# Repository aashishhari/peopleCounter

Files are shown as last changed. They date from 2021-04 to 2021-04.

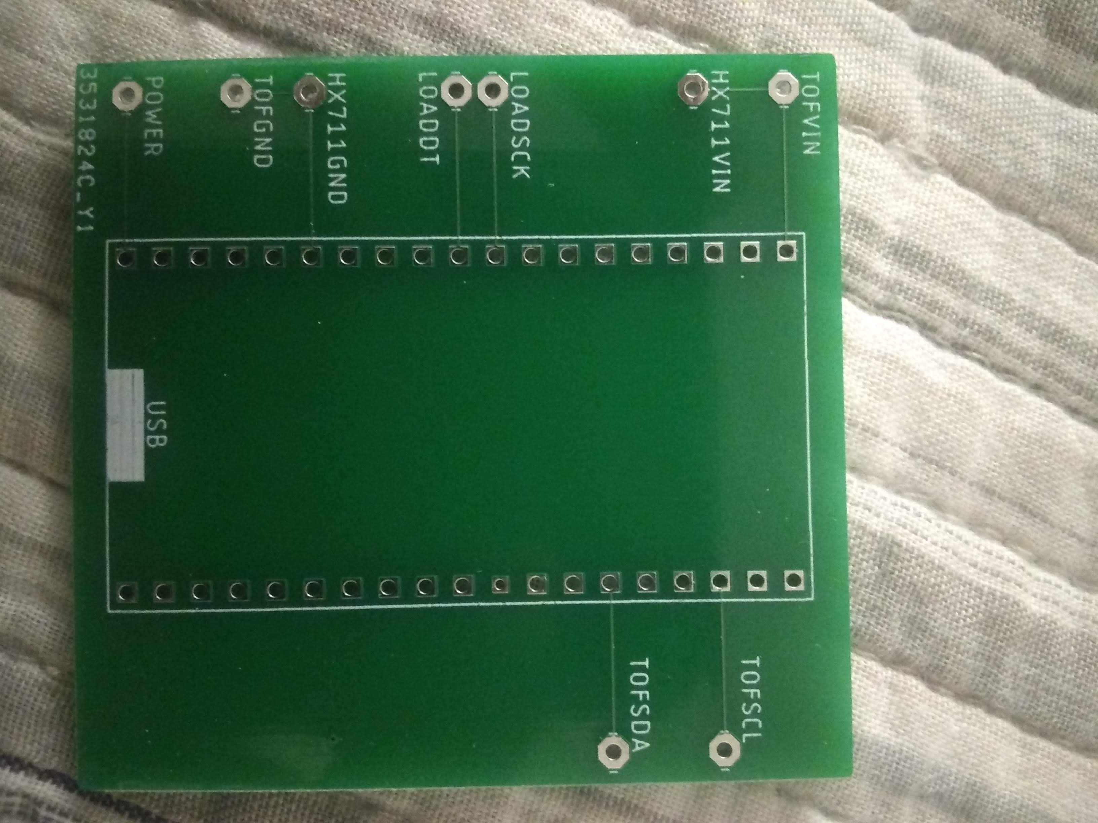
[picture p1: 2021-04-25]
PCB_Photos/PCB.jpg

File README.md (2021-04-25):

# Welcome to Team3's Project Repo for EECS 300

 __In this repo, you'll find our final project code within the `finalDemo` folder.  Note the requirements at the bottom.__
 
 > `EECS300pcb` contains all the parts of the Eagle PCB Project (schematic, pcb view, gerber, drill, etc.).
 
 > `GerberFiles` contains gerber and drill files sent to JLCPCB for final PCB production.
 
 > `TestingData` contains the testing data referenced in our final report.
 
 > `PCB_Photos` contains an image of the final manafactured PCB and also an image of the PCB design in its layered form.

 Additionally, a couple extra files and directories contain a few different implementations we were experimenting with throughout the process.  
 *finalcode_multicore.ino* - contains a prototype multicore version of our design.

__Required Libraries/Dependencies (These need to be installed to run):__
 1. SparkFun_VL53L1X *Version 1.2.9*
 2. Arduino Development Environment (with arduino-esp32 core from Espressif)

__Note: You may need to input WiFi information, SSID, Password, Host ID to compile finalDemo code with no errors__

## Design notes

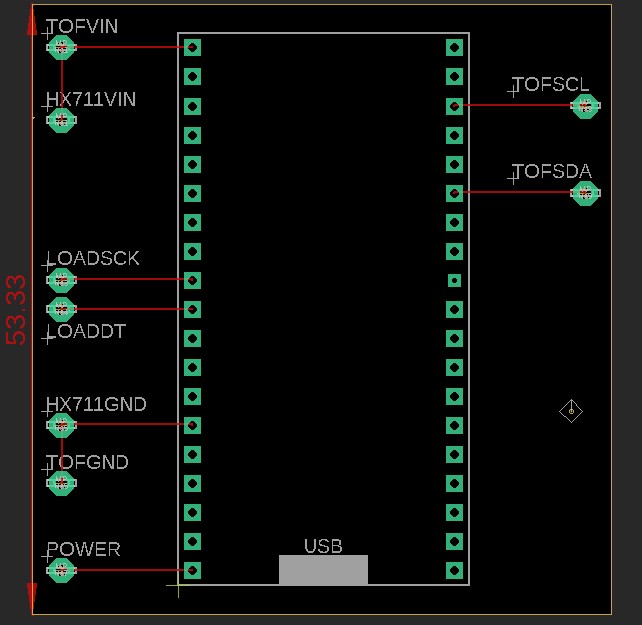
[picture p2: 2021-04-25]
PCB_Photos/PCB_DesignLayers.jpg

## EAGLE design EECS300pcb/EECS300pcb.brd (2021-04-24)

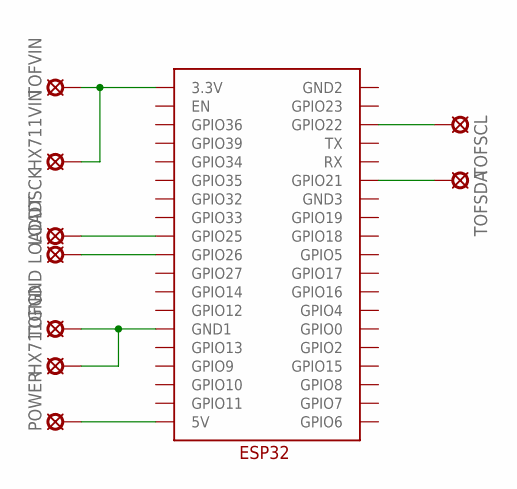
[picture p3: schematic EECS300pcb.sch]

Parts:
HX711GND, HX711VIN: LSP10
LOADDT: LSP10
LOADSCK: LSP10
POWER: LSP10
TOFGND: LSP10
TOFSCL: LSP10
TOFSDA: LSP10
TOFVIN: LSP10
U$2: ESP32

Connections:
unnamed: HX711VIN.MP, TOFVIN.MP, U$2.3.3V
unnamed: LOADSCK.MP, U$2.GPIO25
unnamed: LOADDT.MP, U$2.GPIO26
unnamed: HX711GND.MP, TOFGND.MP, U$2.GND1
unnamed: POWER.MP, U$2.5V
unnamed: TOFSCL.MP, U$2.GPIO22
unnamed: TOFSDA.MP, U$2.GPIO21

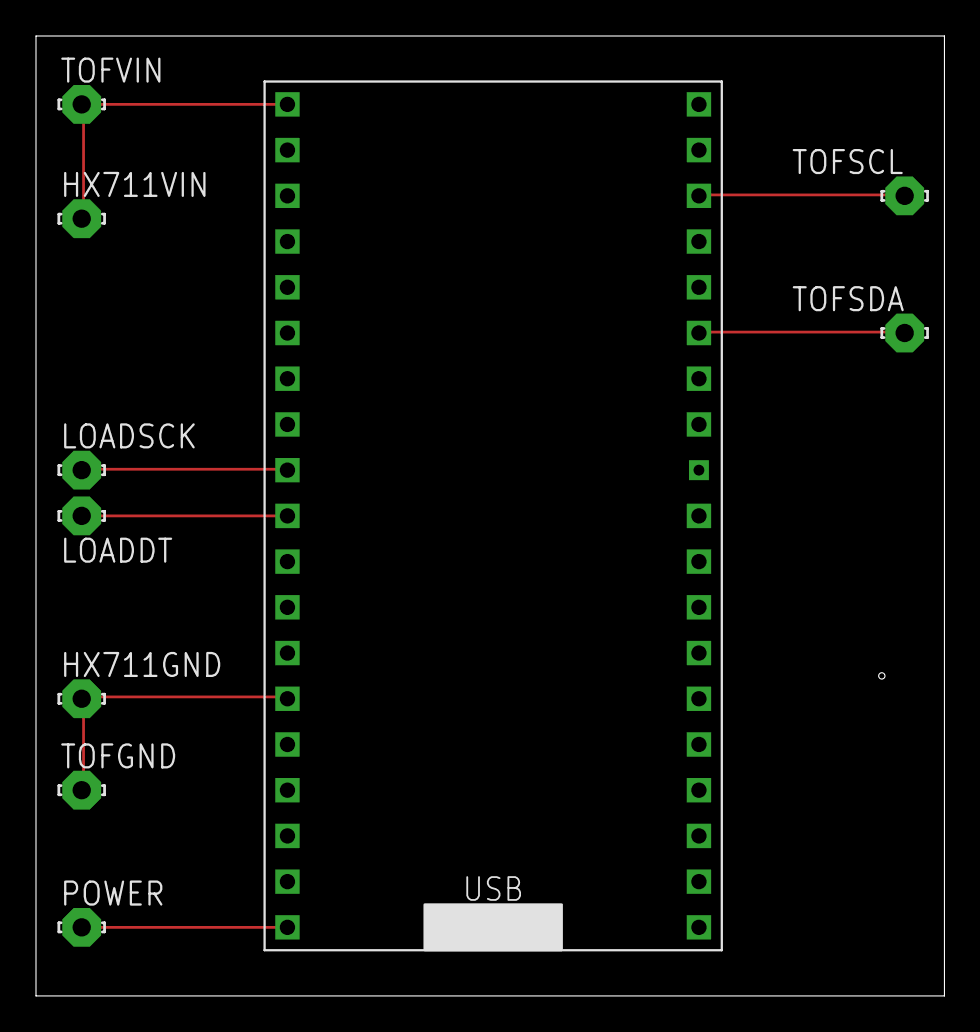
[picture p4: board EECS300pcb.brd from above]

Board: 2 copper layers, 50.5 x 53.3 mm, 10 parts (0 on the bottom side), 7 nets.

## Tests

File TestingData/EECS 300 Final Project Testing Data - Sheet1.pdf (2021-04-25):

Experiment 1 | Description: step around the board a certain amount of times, and determine the edge step efficiency | Size
Trial 1 | Trial 2 | Trial 3 | Darren's board | 28cm x 64cm x 2cm
Registered Steps (Jason)
Resigistered Steps (Darren) | 12 | 12 | 6 | Jason's board
Resigistered Steps (Darren) Day 2 | 12 | 8 | 13
Total Steps | 16 | 16 | 16
Edge step efficiency (%) (Jason)
Edge step efficiency (%) (Darren) | 75 | 75 | 37.5
Edge step efficiency (%) (Darren) | 75 | 50 | 81.25
Average edge step efficiency | 65.625 | (higher is better)
Nptes: | During the second and third trial, my foot almost flipped the wooden board by stepping on the edges of the board, and the board was unable to recognize steps for a few seconds.
| A possible issue is that the board is not the best, because the wooden board I found was kind of old. The board isn't completely level, so we may want to buy another whole set of amazon sensors and buy a brand new board if we want to go with these sensors for the final build.
Experiment 2 | Description: step on a certain spot of the board repeatedly (1 second between each step to let load sensor reset to 0) according to the image to the right
Trial 1 | Trial 2 | Trial 3 | Trial 4 | Trial 5 | Trial 6 | Trial 7 | Trial 8 | Trial 9 (control)
Resigistered Steps (Darren) | 19 | | 20 | | 17 | | 6 | | 20
Resigistered Steps (Jason) | 18 | | 19 | | | | 3 | | 16
Total Steps | 20 | | 20 | | 20 | | 20 | | 20
Edge step efficiency (%) (Darren) | 95 | #DIV/0! | 100 | #DIV/0! | 85 | #DIV/0! | 30 | #DIV/0! | 100
Edge step efficiency (%) (Jason) | 90 | #DIV/0! | 95 | #DIV/0! | 0 | #DIV/0! | 15 | #DIV/0! | 80
Average edge step efficiency | 76.66666667 | | (higher is better)
Notes/conclusions: | Eliminated trials 2, 4, 6, and 8 because we felt that they are already covered by the other 5 trials
| Choosing the right board for the pressure plate is just as important as getting the load sensors working
| The board is not stable, and so we should consider ways to stabilize the board from moving around, while they are getting pressed
| Maybe consider lowering the threshold weight
| Might want to use a sturdier material for final design (not wood)
| Board is acting like a table that is not level (possible issue with Darren's pressure plate)
| It is fine to apply all the weight on one of the four sensors, as long as, an appropriate board is chosen.
Experiment 3 (Darren's trials) | Description: Using a weight lighter than the threshold weight and dropping it in the center of the pressure plate to see if the pressure plate counts weights lighter than the set threshold weight
Trial 1 | Trial 2 | Trial 3
Resigistered Steps (Darren) | 0 | 0 | 0
Resigistered Steps (Jason)
Total Steps | 10 | 10 | 10
Edge step efficiency (%) (Darren) | 0 | 0 | 0
Edge step efficiency (%) (Jason) | 0 | 0 | 0
Average edge step efficiency | 0 | | (lower is better)
Nptes: | Seems like the pressure plate does not have any issues with not making accidental counts when a weight lower than the threshold has been put on it.

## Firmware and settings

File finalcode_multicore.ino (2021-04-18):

#include "hal.h"
#include "HX711.h"
#include "soc/rtc.h"
#include "hal.h"

#include <Wire.h>
#include <SparkFun_VL53L1X.h>
#include <WiFi.h>

/* Multicore */
TaskHandle_t main;
TaskHandle_t wifiUpdate;
void main(void *pvParameters);
void wifiUpdate(void *pvParameters);
/** done **/

/** WIFI Globals **/
const char* ssid = "NETGEAR92";
const char* password =  "youngtrumpet129";
const uint16_t port = 8090;
const char * host = "192.168.1.16";
WiFiClient client;
/** done **/

/** TOF Globals **/
static const int NOBODY = 0;
static const int SOMEONE = 1;
static const int LEFT = 0;
static const int RIGHT = 1;
static int center[2] = {167, 231}; // andrea's suggested value also try
int zone = 0;

#define DIST_THRESHOLD                               1600  // mm
#define ROWS_OF_SPADS                                4 // 8x16 SPADs ROI
#define TIMING_BUDGET                                33  // was 20 ms, I found 33 ms has better succes rate with lower reflectance target
#define ROI_WIDTH                                    4
#define ROI_HEIGHT                                   4
SFEVL53L1X sensor(Wire);
int ProcessPeopleCountingData(int16_t Distance, uint8_t zone);
int tofCount = 0;
int tofOldCount = 0;
/** done **/

/** Load Sensor Globals **/
HX711 scale;
float threshold = 1000; // kg
float reading = 0;
float prevReading = 0;
/** done **/

/** FINAL CODE Globals **/
volatile int people = 0; // for multicore operation
volatile int oldpeoplecount = 0; // "same as ^", is this necessary tho?
int lastactive = 0;
int lastbothactive = 0;
int timeBetweenActivation = 3000;
int timeBetweenBothTrigger = 500;
int loadtime = 0;
int toftime = 0;
/** done **/

void setup() {
  Serial.begin(9600);
  
  /* SERVER Setup */
  WiFi.begin(ssid, password);
  while (WiFi.status() != WL_CONNECTED) {
    delay(500);
    Serial.println("...");
  }
  Serial.print("WiFi connected with IP: ");
  Serial.println(WiFi.localIP());

  xTaskCreatePinnedToCore( // Pin Wifi Sends to Core 0
    sendwifi,   /* Task function. */
    "wifiUpdate",     /* name of task. */
    10000,       /* Stack size of task */
    NULL,        /* parameter of the task */
    1,           /* priority of the task */
    &wifi,      /* Task handle to keep track of created task */
    0);          /* pin task to core 0 */                  
  delay(500); 
  /* --- */

  /* 1. Setup Load Sensor */
  /* Notes:
  parameter "gain" is ommited; the default value 128 is used by the library 
  HX711.DOUT  - pin #A1
  HX711.PD_SCK - pin #A0
  */
  rtc_clk_cpu_freq_set(RTC_CPU_FREQ_80M);
  Serial.println("Initializing the scale");
  scale.begin(26, 25);

  Serial.println("Before setting up the scale:");
  Serial.print("read: \t\t");
  Serial.println(scale.read());     // print a raw reading from the ADC

  Serial.print("read average: \t\t");
  Serial.println(scale.read_average(20));   // print the average of 20 readings from the ADC

  Serial.print("get value: \t\t");
  Serial.println(scale.get_value(5));   // print the average of 5 readings from the ADC minus the tare weight (not set yet)

  Serial.print("get units: \t\t");
  Serial.println(scale.get_units(5), 1);  // print the average of 5 readings from the ADC minus tare weight (not set) divided
  // by the SCALE parameter (not set yet)

  scale.set_scale(50);    // this value is obtained by calibrating the scale with known weights; see the README for details
  scale.tare();               // reset the scale to 0

  Serial.println("After setting up the scale:");

  Serial.print("read: \t\t");
  Serial.println(scale.read());                 // print a raw reading from the ADC

  Serial.print("read average: \t\t");
  Serial.println(scale.read_average(20));       // print the average of 20 readings from the ADC

  Serial.print("get value: \t\t");
  Serial.println(scale.get_value(5));   // print the average of 5 readings from the ADC minus the tare weight, set with tare()

  Serial.print("get units: \t\t");
  Serial.println(scale.get_units(5), 1);        // print the average of 5 readings from the ADC minus tare weight, divided
  // by the SCALE parameter set with set_scale

  Serial.println("Readings:");
  /* --- */

  /* SETUP TOF SENSOR */
  Wire.begin();
  Wire.setClock(400000); // use 400 kHz I2C 0x52
  if (sensor.begin()) { // init() is deprecated()
    Serial.println("Error Connecting to Sensor");
    while(1); // !!!!!!!!!!!!!!!!!!!!!!!!!!!!!!!!!!!!!!!!!!!!!!!!!!!!!!!!!!!!!!!!!!!!! oh maybe I can fix this...do a loop type thing.
  }
  Serial.println("Success connecting to sensor");
  sensor.setDistanceModeLong(); // modify this mode.
  sensor.setTimingBudgetInMs(TIMING_BUDGET);
  sensor.setIntermeasurementPeriod(TIMING_BUDGET+4); // The minimum inter-measurement period must be longer than the timing budget + 4 ms - UM2356 (perhaps we can get away with 1 we'll see)
  sensor.setROI(ROI_WIDTH,ROI_HEIGHT,center[zone]);
  sensor.startRanging();
  Serial.println("Starting...");
  /* --- */

  xTaskCreatePinnedToCore( // Running on Core #1
    main,   /* Task function. */
    "main",     /* name of task. */
    10000,       /* Stack size of task */
    NULL,        /* parameter of the task */
    1,           /* priority of the task */
    &main,      /* Task handle to keep track of created task */
    1);          /* pin task to core 1 */
  delay(500);
}

void main(void * pvParameters) {
  Serial.print("Task2 running on core ");
  Serial.println(xPortGetCoreID());

  for(;;){
    // prevReading = reading; (threshold thing.)
    reading = scale.get_units(1);
    Serial.println(reading); // consider alternate approach as well if this works.
    if(reading > threshold) { // maybe include a boolean check to see if the TOF is picking up something also
    //peepcount = peepcount + 1;
      loadtime = millis(); //Serial.println(peepcount); //delay(100);
    }

      //2. perform one iteration of the tof: returns the last time it was triggered
    if(sensor.checkForDataReady()) {
      int16_t distance = sensor.getDistance();
      sensor.clearInterrupt();
      tofCount = ProcessPeopleCountingData(distance,zone,rangeStatus);
      zone = zone + 1;
      zone = zone % 2;
      sensor.setROI(ROI_WIDTH,ROI_HEIGHT, center[zone]);
    }
    if(oldCount != count) {
      toftime = millis();
    }
    tofOldCount = tofCount;

    if (loadtime == 0 && toftime == 0 || (millis() - lastbothactive < timeBetweenBothTrigger)) {
    // do nothing
    }
    else if (loadtime != 0 && toftime == 0) {
      lastactive = loadtime;
    }
    else if (loadtime == 0 && toftime != 0) {
      lastactive = toftime;
    }
    else {
      int bothactive = millis();
      Serial.println(bothactive - lastactive);
      if (bothactive - lastactive < timeBetweenActivation) { // difference between this & trigger ^?
        if (toftime - loadtime > 1500) {
          people++;
          Serial.println(people);
        }
        else {
          if(people > 0) {
            people--;
        } 
          Serial.println(people);
        }
        lastbothactive = bothactive;
        loadtime = 0;
        toftime = 0;
      }
      else {
        lastactive = bothactive;
        if(toftime > loadtime) {
          loadtime = 0;
        }
        else {
          toftime = 0;
        }
      }
    }
  }
}

//float reading = 0;
// float prevReading = 0;
void loop() {

}

// separate core wifi implementation
void wifiUpdate(void * pvParameters) {
  Serial.print("WifiUpdate running on core ");
  Serial.println(xPortGetCoreID());
  for(;;) {
    if(oldpeoplecount != people) {
      oldpeoplecount = people;
      if(!client.connect(host, port)) {
        Serial.println("Connection to host failed");
        delay(1000);
      }
      Serial.println("Connected to server successful!");
      client.print(people);
      Serial.println("Disconnecting...");
      client.stop();
    }
  }
}

int ProcessPeopleCountingData(int16_t Distance, uint8_t zone) {
  static int PathTrack[] = {0,0,0,0};
  static int PathTrackFillingSize = 1; // init this to 1 as we start from state where nobody is any of the zones
  static int LeftPreviousStatus = NOBODY;
  static int RightPreviousStatus = NOBODY;
  static int PeopleCount = 0; // remember this is GLOBAL!

  int CurrentZoneStatus = NOBODY;
  int AllZonesCurrentStatus = 0;
  int AnEventHasOccured = 0;

  if (MinDistance < DIST_THRESHOLD) {
    // Someone is in !
    CurrentZoneStatus = SOMEONE;
  }
  // left zone
  if (zone == LEFT) {
    if (CurrentZoneStatus != LeftPreviousStatus) {
      // event in left zone has occured
      AnEventHasOccured = 1;
      
      if (CurrentZoneStatus == SOMEONE) {
        AllZonesCurrentStatus += 1;
      }
      // need to check right zone as well ...
      if (RightPreviousStatus == SOMEONE) {
        // event in right zone has occured
        AllZonesCurrentStatus += 2;
      }
      // remember for next time
      LeftPreviousStatus = CurrentZoneStatus;
    }
  }
  // right zone
  else {
    if (CurrentZoneStatus != RightPreviousStatus) {
      // event in right zone has occured
      AnEventHasOccured = 1;
      if (CurrentZoneStatus == SOMEONE) {
        AllZonesCurrentStatus += 2;
      }
      // need to left right zone as well ...
      if (LeftPreviousStatus == SOMEONE) {
        // event in left zone has occured
        AllZonesCurrentStatus += 1;
      }
      // remember for next time
      RightPreviousStatus = CurrentZoneStatus;
    }
  }
  // if an event has occured
  if (AnEventHasOccured) {
    if (PathTrackFillingSize < 4) {
      PathTrackFillingSize++;
    }
    
    // if nobody anywhere lets check if an exit or entry has happened
    if ((LeftPreviousStatus == NOBODY) && (RightPreviousStatus == NOBODY)) {
      // check exit or entry only if PathTrackFillingSize is 4 (for example 0 1 3 2) and last event is 0 (nobobdy anywhere)
      if (PathTrackFillingSize == 4) {
        // check exit or entry. no need to check PathTrack[0] == 0 , it is always the case NOBODY
        if ((PathTrack[1] == 1)  && (PathTrack[2] == 3) && (PathTrack[3] == 2)) {
          // This an entry
          PeopleCount = PeopleCount + 1;
          // reset the table filling size in case an entry or exit just found
          Serial.print("Walk In, People Count=");
          Serial.println(PeopleCount);
        } else if ((PathTrack[1] == 2)  && (PathTrack[2] == 3) && (PathTrack[3] == 1)) {
          // This an exit
          PeopleCount = PeopleCount - 1;
          // reset the table filling size in case an entry or exit just found
          Serial.print("Walk Out, People Count="); 
          Serial.println(PeopleCount);
        } else {
          // reset the table filling size also in case of unexpected path
          Serial.println("Wrong path");
        }
      }
      PathTrackFillingSize = 1;
    }
    else {
      // update PathTrack
      // example of PathTrack update
      // 0
      // 0 1
      // 0 1 3
      // 0 1 3 1
      // 0 1 3 3
      // 0 1 3 2 ==> if next is 0 : check if exit
      PathTrack[PathTrackFillingSize-1] = AllZonesCurrentStatus;
    }
  }
  return PeopleCount;
}

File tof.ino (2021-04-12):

#include <Wire.h>
#include <SparkFun_VL53L1X.h>

#define SHUTDOWN_PIN 2 //idk
#define INTERRUPT_PIN 3 //idk


const int threshold_percentage = 80;

char peopleCounterArray[50];

static const int NOBODY = 0;
static const int SOMEONE = 1;
static const int LEFT = 0;
static const int RIGHT = 1;

static int center[2] = {167, 231}; // andrea's suggested value also try
int zone = 0;

// Specific to our Profile
#define PROFILE_STRING                               "DOOR_JAM_2400"
#define DISTANCES_ARRAY_SIZE                         10   // nb of samples
#define MAX_DISTANCE                                 2400 // mm, 2000
#define MIN_DISTANCE                                 0   // mm
#define DIST_THRESHOLD                               850  // mm, 1600
#define ROWS_OF_SPADS                                8 // 8x16 SPADs ROI
#define TIMING_BUDGET                                33  // was 20 ms, I found 33 ms has better succes rate with lower reflectance target, ignor eusing 50
#define DISTANCE_MODE                                DISTANCE_MODE_LONG

SFEVL53L1X sensor(Wire);

//void zonesCalibration();
int ProcessPeopleCountingData(int16_t Distance, uint8_t zone, uint8_t RangeStatus);
int oldCount = 0;
void setup() {
  Serial.begin(115200);
  Wire.begin();
  Wire.setClock(400000); // use 400 kHz I2C

  // Failure Mode 1
  if (sensor.begin()) // init() is deprecated version
  {
    Serial.println("Error Connecting to Sensor");
    while(1);
  }
  Serial.println("Success connecting to sensor");
  
  // Minimum timing budget is 20ms for short distance mode and 33ms for medium & long distance modes ==> Check datasheet for more details.
  sensor.setDistanceModeLong(); // discrete set of supported measurement frequencies for ULD [20 33 50 100] [15, 20, 33, 50, 100, 200, 500] , don't think 15 is actually allowed, 66 Hz max ranging, 33 ms min for our application
  sensor.setTimingBudgetInMs(33); // timing budget for measurement

  // Start continuous readings at a rate of one measurement every 50 ms (the inter-measurement period). 
  // This period should be at least as long as the timing budget.
  sensor.setIntermeasurementPeriod(34); // time between measurements. (Delay between Ranging operations)
  sensor.setROI(4,4,center[zone]);

  // sensor zone calibration -- ok this is how we get the zonedata, to implement later (add next line there as well)
  sensor.startRanging();
  Serial.println("Starting...");
}

// use millis() instead of delay()https://dzone.com/articles/arduino-using-millis-instead-of-delay

void loop() {
  // put your main code here, to run repeatedly:
  if(sensor.checkForDataReady()) {
    //sensor.setDistanceThreshold(100,300,3); 
    //setDist(dev,100,300,0,1): below 100 ||| setDist(dev,100,300,1,1): above 300 ||| setDist(dev,100,300,2,1): out-of-window ||| setDist(dev,100,300,3,1): in window
    uint16_t rangeStatus = sensor.getRangeStatus();
    int16_t distance = sensor.getDistance(); //uint.
    sensor.clearInterrupt();
//    Serial.print("Center ");
//    Serial.print(center[zone]);
//    Serial.print(" Distance: ");
//    Serial.println(distance);
    int count = ProcessPeopleCountingData(distance,zone,rangeStatus);
    if(!count) {
      Serial.print(count);
    } else {
      Serial.println();
      Serial.print("Count: ");
      Serial.println(count);
      oldCount = count;
    }
    zone = zone + 1;
    zone = zone % 2;
    sensor.setROI(4,4, center[zone]);
    
  }
}

int ProcessPeopleCountingData(int16_t Distance, uint8_t zone, uint8_t RangeStatus) {
  static int PathTrack[] = {0,0,0,0};
  static int PathTrackFillingSize = 1; // init this to 1 as we start from state where nobody is any of the zones
  static int LeftPreviousStatus = NOBODY;
  static int RightPreviousStatus = NOBODY;
  static int PeopleCount = 0;
  static uint16_t Distances[2][DISTANCES_ARRAY_SIZE];
  static uint8_t DistancesTableSize[2] = {0,0};

  uint16_t MinDistance;
  uint8_t i;
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

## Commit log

2021-04-15 some cleanup/removal in original tof, also starting work on a nonloop, timer version
2021-04-18 added a suggestion for laod sensor logic, deleted some comments
2021-04-24 PCB files added
    [EECS300pcb.brd, EECS300pcb.sch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]
